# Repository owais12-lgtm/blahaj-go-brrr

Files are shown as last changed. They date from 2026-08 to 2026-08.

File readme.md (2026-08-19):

# Bluetooth jammer 
DISCLAIMER: This project is for educational and security research purposes only. The user is solely responsible for compliance with local laws regarding radio interference

This is a small 44 x 60 mm 2.4ghz wifi and Bluetooth jammer/deauther. It uses an ESP32 and two nRF24L01+PA+LNA! It's based on a video I came across on YouTube where someone made a similar project. 
 # PCB


 # 3D view 



# schematic 


# BOM

| Name | Qty | Price (USD) | Vendor |
| --- | ---: | ---: | --- |
| NRF24L01+PA+LNA | 2 | 4 | Robu |  https://robu.in/product/2-4ghz-nrf24l01palna-sma-antenna-wireless-transceiver-communication-module-1km/
| ESP32-DEVKITV1 | 1 | 12.5 | robu | https://robu.in/product/espressif-esp32-devkitm-1-development-board/
| 100uF Electrolytic Capacitor | 2 | 0.6 | robu |  https://robu.in/product/100uf-25v-electrolytic-capacitor-pack-of-10/
| PCB | 1 | 10 | Robu | https://robu.in/product/online-pcb-manufacturing-service/
| Total | 6 | 31.7 | - |.

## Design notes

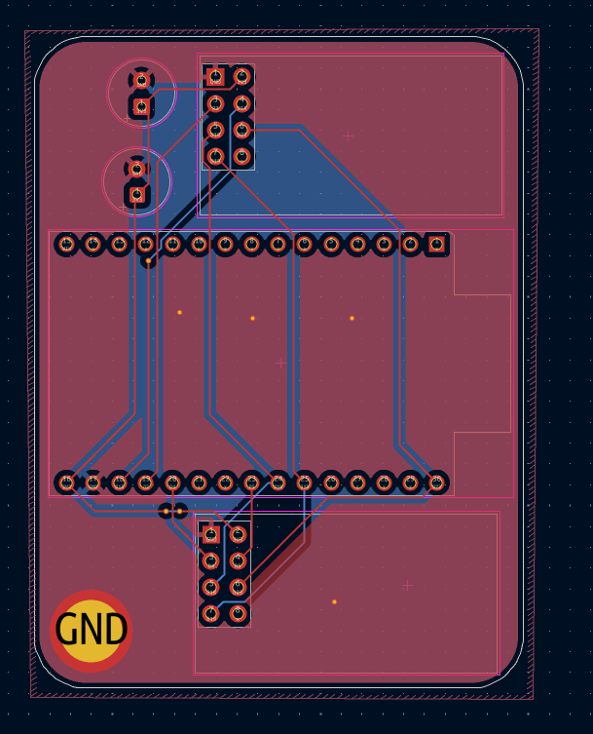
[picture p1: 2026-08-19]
images/image-1 (Copy).png

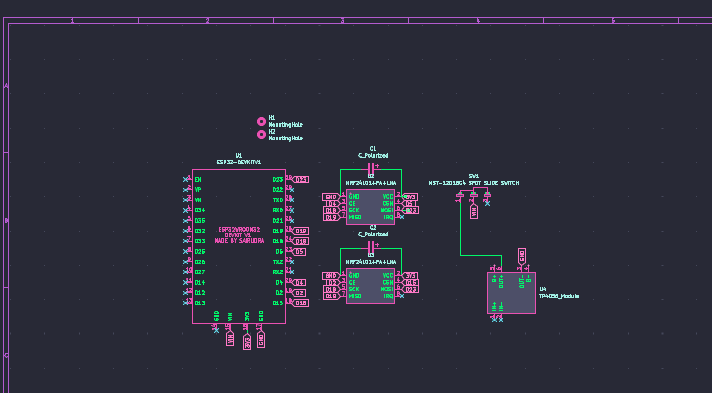
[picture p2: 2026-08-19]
images/image.png

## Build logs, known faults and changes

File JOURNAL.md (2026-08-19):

---
title: "Bluetooth jammer"
description: This is a small 44 x 60 mm Bluetooth jammer built with an ESP-32 and NRF24L01 modules! 
created_at: 2026-8-18
---

# Aug 18th: uh pcb + sch 
 
this journal entry, I worked on basically the entire project. I watched a YouTube video about Bluetooth jammers and how cheap they seem to be, and incredibly simple too.  I took quite a bit of time trying to find footprints for nRF modules. Then I made the circuit based on the vid I watched. After this, I went through 2 iterations of the PCB and settled on this final version and added some cool silkscreen art. 

For the first iteration, I didn't really like the shape of the PCB cuz it was like really really long cuz of the antenna, and the PCB was generally long too, so I moved to a layout where the nRF modules were on the sides of the esp 32 








Screenshot from 2026-08-19 20-26-50



**Total time spent: 2h**

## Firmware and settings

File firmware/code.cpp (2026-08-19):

#include "RF24.h"
#include <SPI.h>
#include "esp_bt.h"
#include "esp_wifi.h"

// --- HARDWARE CONFIGURATION ---
// NRF24 Module 1 Pins (shares VSPI bus)
#define NRF24_1_CE_PIN      4
#define NRF24_1_CSN_PIN     5

// NRF24 Module 2 Pins (shares VSPI bus)
#define NRF24_2_CE_PIN      2
#define NRF24_2_CSN_PIN     15

// SPI Clock Speed for NRF24
#define SPI_CLOCK_SPEED     16000000UL

// LED Pin for status indication
const int LED_PIN = 2;

// LED Blink Interval (milliseconds)
const unsigned long LED_BLINK_INTERVAL_MS = 500;

// RF24 Channel Range (0-80)
const uint8_t CHANNEL_MIN = 0;
const uint8_t CHANNEL_MAX = 80;


// --- Global Objects ---
SPIClass *vspi_bus = nullptr;

RF24 radioModule1(NRF24_1_CE_PIN, NRF24_1_CSN_PIN, SPI_CLOCK_SPEED);
RF24 radioModule2(NRF24_2_CE_PIN, NRF24_2_CSN_PIN, SPI_CLOCK_SPEED);

uint8_t currentChannelModule1 = CHANNEL_MIN;
uint8_t currentChannelModule2 = (CHANNEL_MIN + (CHANNEL_MAX - CHANNEL_MIN) / 2);

// --- Function Prototypes ---
void initializeSystemPeripherals();
void setupSPIBus();
void configureNRF24Module(RF24& radio, SPIClass* spiBus, const char* moduleName);
void fastChannelSweep();
void toggleStatusLED();

// --- Setup Function ---
void setup() {
    Serial.begin(115200);

    pinMode(LED_PIN, OUTPUT);
    digitalWrite(LED_PIN, LOW);

    initializeSystemPeripherals();
    setupSPIBus();

    bool module1_ok = true;
    if (vspi_bus) {
        configureNRF24Module(radioModule1, vspi_bus, "Module 1");
        if (!radioModule1.isChipConnected()) {
            module1_ok = false;
        }
    } else {
        module1_ok = false;
    }

    bool module2_ok = true;
    if (vspi_bus) {
        configureNRF24Module(radioModule2, vspi_bus, "Module 2");
        if (!radioModule2.isChipConnected()) {
            module2_ok = false;
        }
    } else {
        module2_ok = false;
    }

    if (!module1_ok && !module2_ok) {
        Serial.println("FATAL ERROR: Both NRF24 modules failed. Jammer halted.");
        while (true) {
            digitalWrite(LED_PIN, HIGH); delay(100);
            digitalWrite(LED_PIN, LOW);  delay(100);
        }
    } else if (!module1_ok) {
        Serial.println("WARNING: NRF24 Module 1 failed. Operating with Module 2 only.");
    } else if (!module2_ok) {
        Serial.println("WARNING: NRF24 Module 2 failed. Operating with Module 1 only.");
    }
}

// --- Main Loop Function ---
void loop() {
    fastChannelSweep();
    toggleStatusLED();
}


// --- Helper Functions ---

void initializeSystemPeripherals() {
    esp_bt_controller_deinit();
    esp_wifi_stop();
    esp_wifi_deinit();
    esp_wifi_disconnect();
}

void setupSPIBus() {
    vspi_bus = new SPIClass(VSPI);
    vspi_bus->begin();
}

void configureNRF24Module(RF24& radio, SPIClass* spiBus, const char* moduleName) {
    if (spiBus == nullptr) {
        return;
    }
    if (!radio.begin(spiBus)) {
        return;
    }

    radio.setAutoAck(false);
    radio.stopListening();
    radio.setRetries(0, 0);
    radio.setPALevel(RF24_PA_MAX, true);
    radio.setDataRate(RF24_2MBPS);
    radio.setCRCLength(RF24_CRC_DISABLED);

    uint8_t initialChannel;
    if (strcmp(moduleName, "Module 1") == 0) {
        initialChannel = currentChannelModule1;
    } else {
        initialChannel = currentChannelModule2;
    }
    radio.startConstCarrier(RF24_PA_MAX, initialChannel);
}

void fastChannelSweep() {
    if (radioModule1.isChipConnected()) {
        currentChannelModule1++;
        if (currentChannelModule1 > CHANNEL_MAX) {
            currentChannelModule1 = CHANNEL_MIN;
        }
        radioModule1.setChannel(currentChannelModule1);
    }

    if (radioModule2.isChipConnected()) {
        currentChannelModule2++;
        if (currentChannelModule2 > CHANNEL_MAX) {
            currentChannelModule2 = CHANNEL_MIN;
        }
        radioModule2.setChannel(currentChannelModule2);
    }
    delayMicroseconds(200);
}

void toggleStatusLED() {
    static unsigned long lastToggleTime = 0;
    static bool ledState = false;

    unsigned long currentTime = millis();
    if (currentTime - lastToggleTime >= LED_BLINK_INTERVAL_MS) {
        lastToggleTime = currentTime;
        ledState = !ledState;
        digitalWrite(LED_PIN, ledState ? HIGH : LOW);
    }
}

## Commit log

2026-08-19 Add PCB image to readme
    Added PCB image section to the readme.
2026-08-19 bom go kaboooooom
    kablow
    [BOM.csv]
